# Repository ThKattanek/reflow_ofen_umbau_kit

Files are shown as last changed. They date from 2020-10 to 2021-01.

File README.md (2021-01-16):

# Reflow Ofen Umbau Kit
Mit dem „Reflow Ofen Umbau Kit“ (in Zukunft „Kit“ genannt) kann man einen alten Pizza Ofen zu einem Reflow Ofen umfunktionieren. Das Kit beinhaltet die komplette Mikrocontroller gestützte Steuerung und das entsprechende Netzteil welches die 5V und 12V bereitstellt. Dieses Kit ist für Hobbyelektroniker gedacht die hin und wieder eine Platine mit SMD Bauteilen löten wollen, jedoch eine Anschaffung eines Reflows Ofens zu kostenintensiv ist.

### [Letzte Offizelle Version findet ihr hier](https://github.com/ThKattanek/reflow_ofen_umbau_kit/releases/latest)

### YouTube Videos vom Projekt
|1.Teil|2.Teil|3.Teil|4.Teil|5.Teil|
|---|---|---|---|---|
|[](http://www.youtube.com/watch?v=8IvjsnkUP-0 "Projekt Reflow Ofen Teil 1")|[](http://www.youtube.com/watch?v=AaKD-QuOhvM "Projekt Reflow Ofen Teil 2")|[](http://www.youtube.com/watch?v=eux7afdVVEE  "Projekt Reflow Ofen Teil 3")|[](http://www.youtube.com/watch?v=xKUIrKcyTKQ "Projekt Reflow Ofen Teil 4")|[](http://www.youtube.com/watch?v=lzVyeRATymM "Projekt Reflow Ofen Teil 5")
### Hardware / Schaltplan
Die Hardware wurde mit KiCad entwickelt. Version 5.1.7 unter Ubuntu.

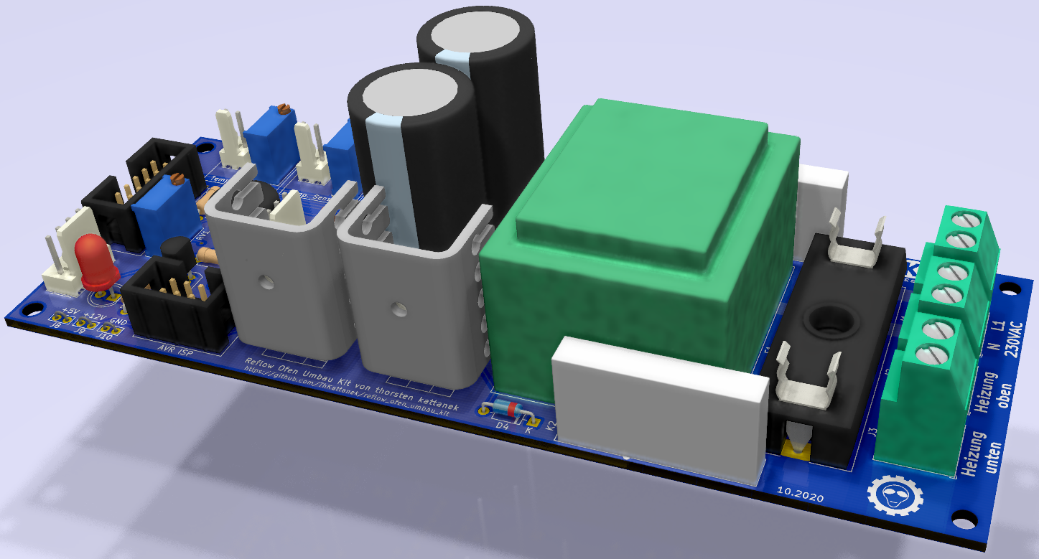
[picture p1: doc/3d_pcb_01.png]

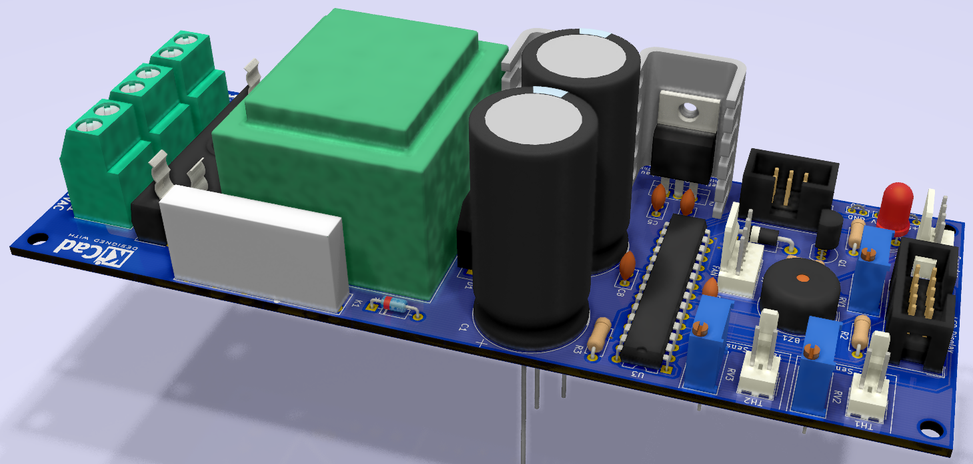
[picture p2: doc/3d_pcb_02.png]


### PCB
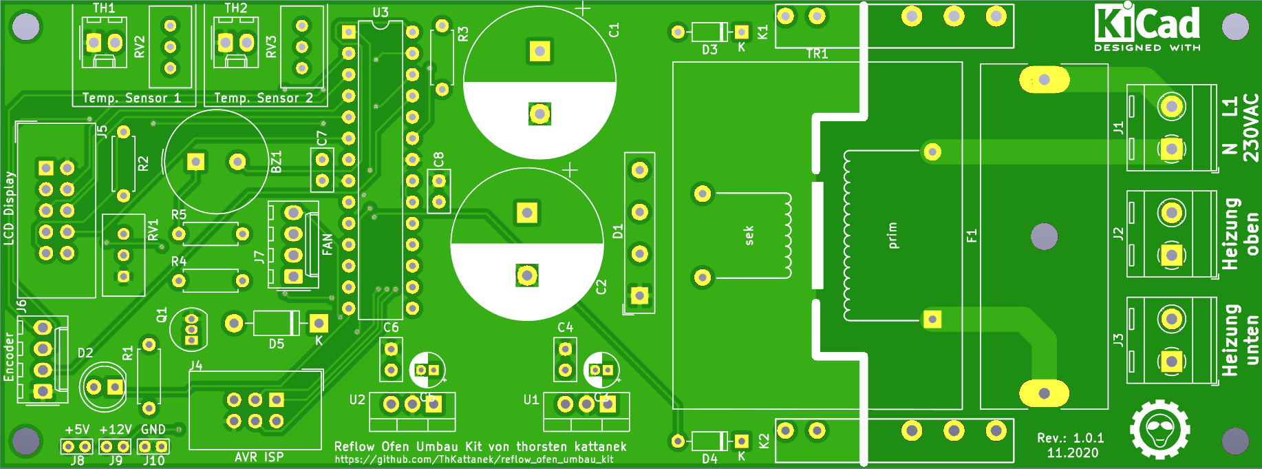
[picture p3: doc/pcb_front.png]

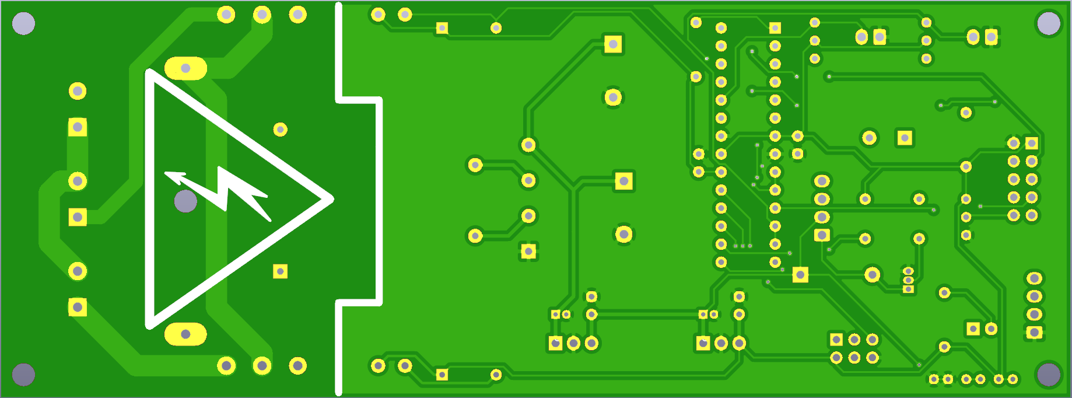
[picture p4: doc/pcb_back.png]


### Verwendete Libs
LCD Ansteuerung von Mikrokontroller.net: http://www.mikrocontroller.net/articles/AVR-GCC-Tutorial/LCD-Ansteuerung

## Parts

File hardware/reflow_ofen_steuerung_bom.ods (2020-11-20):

Reference | Quantity | Value | Footprint | Datasheet
BZ1 | 1 | Buzzer | Buzzer_Beeper:Buzzer_TDK_PS1240P02BT_D12.2mm_H6.5mm | ~
C1 C2 | 2 | 10m | Capacitor_THT:CP_Radial_D18.0mm_P7.50mm | ~
C3 C5 | 2 | 0,33u | Capacitor_THT:CP_Radial_D4.0mm_P1.50mm | ~
C4 C6 C7 C8 | 4 | 100n | Capacitor_THT:C_Disc_D5.0mm_W2.5mm_P2.50mm | ~
D1 | 1 | B40C2300-1500A | Diode_THT:Diode_Bridge_Vishay_GBL | https://diotec.com/tl_files/diotec/files/pdf/datasheets/b40c2300.pdf
D2 | 1 | LED | LED_THT:LED_D5.0mm | ~
D3 D4 | 2 | 1N4148 | Diode_THT:D_DO-35_SOD27_P7.62mm_Horizontal | https://assets.nexperia.com/documents/data-sheet/1N4148_1N4448.pdf
D5 | 1 | 1N4001 | Diode_THT:D_DO-41_SOD81_P10.16mm_Horizontal | http://www.vishay.com/docs/88503/1n4001.pdf
F1 | 1 | Fuse | Fuse:Fuseholder_Cylinder-6.3x32mm_Schurter_0031-8002_Horizontal_Open | ~
J1 | 1 | 230VAC | TerminalBlock_RND:TerminalBlock_RND_205-00287_1x02_P5.08mm_Horizontal | ~
J10 | 1 | GND | TestPoint:TestPoint_Bridge_Pitch2.0mm_Drill0.7mm | ~
J2 | 1 | Heizung oben | TerminalBlock_RND:TerminalBlock_RND_205-00287_1x02_P5.08mm_Horizontal | ~
J3 | 1 | Heizung unten | TerminalBlock_RND:TerminalBlock_RND_205-00287_1x02_P5.08mm_Horizontal | ~
J4 | 1 | AVR-ISP-6 | Connector_IDC:IDC-Header_2x03_P2.54mm_Vertical | ~
J5 | 1 | LCD Display | Connector_IDC:IDC-Header_2x05_P2.54mm_Vertical | ~
J6 | 1 | Encoder | Connector_Molex:Molex_KK-254_AE-6410-04A_1x04_P2.54mm_Vertical | ~
J7 | 1 | FAN | Connector_Molex:Molex_KK-254_AE-6410-04A_1x04_P2.54mm_Vertical | ~
J8 | 1 | +5V | TestPoint:TestPoint_Bridge_Pitch2.0mm_Drill0.7mm | ~
J9 | 1 | +12V | TestPoint:TestPoint_Bridge_Pitch2.0mm_Drill0.7mm | ~
K1 K2 | 2 | FTR-LY_Cxxx | relay_tk:FTR-LY_Cxxx | ${TK_DATASHEETS}/FTR-LY.pdf
Q1 | 1 | BC337 | Package_TO_SOT_THT:TO-92_Inline | https://diotec.com/tl_files/diotec/files/pdf/datasheets/bc337.pdf
R1 | 1 | 1,5k | Resistor_THT:R_Axial_DIN0207_L6.3mm_D2.5mm_P7.62mm_Horizontal | ~
R2 R5 | 2 | 150 | Resistor_THT:R_Axial_DIN0207_L6.3mm_D2.5mm_P7.62mm_Horizontal | ~
R3 | 1 | 10k | Resistor_THT:R_Axial_DIN0207_L6.3mm_D2.5mm_P7.62mm_Horizontal | ~
R4 | 1 | 220 | Resistor_THT:R_Axial_DIN0207_L6.3mm_D2.5mm_P7.62mm_Horizontal | ~
RV1 RV2 RV3 | 3 | 10k | Potentiometer_THT:Potentiometer_Bourns_3296W_Vertical | ~
TH1 TH2 | 2 | KTY84-130 | Connector_Molex:Molex_KK-254_AE-6410-02A_1x02_P2.54mm_Vertical | http://cache.nxp.com/documents/data_sheet/KTY84_SER.pdf?pspll=1
TR1 | 1 | GERTH_12V_3.6VA | transformer_tk:Transformer_NF_GERTH_387.12-1 | ${TK_DATASHEETS}/GERTH_DATA_TYPE-387.pdf
U1 | 1 | L7812 | Package_TO_SOT_THT:TO-220-3_Vertical | http://www.st.com/content/ccc/resource/technical/document/datasheet/41/4f/b3/b0/12/d4/47/88/CD00000444.pdf/files/CD00000444.pdf/jcr:content/translations/en.CD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
U2 | 1 | L7805 | Package_TO_SOT_THT:TO-220-3_Vertical | http://www.st.com/content/ccc/resource/technical/document/datasheet/41/4f/b3/b0/12/d4/47/88/CD00000444.pdf/files/CD00000444.pdf/jcr:content/translations/en.CD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
U3 | 1 | ATmega8-16PU | Package_DIP:DIP-28_W7.62mm | http://ww1.microchip.com/downloads/en/DeviceDoc/atmel-2486-8-bit-avr-microcontroller-atmega8_l_datasheet.pdf

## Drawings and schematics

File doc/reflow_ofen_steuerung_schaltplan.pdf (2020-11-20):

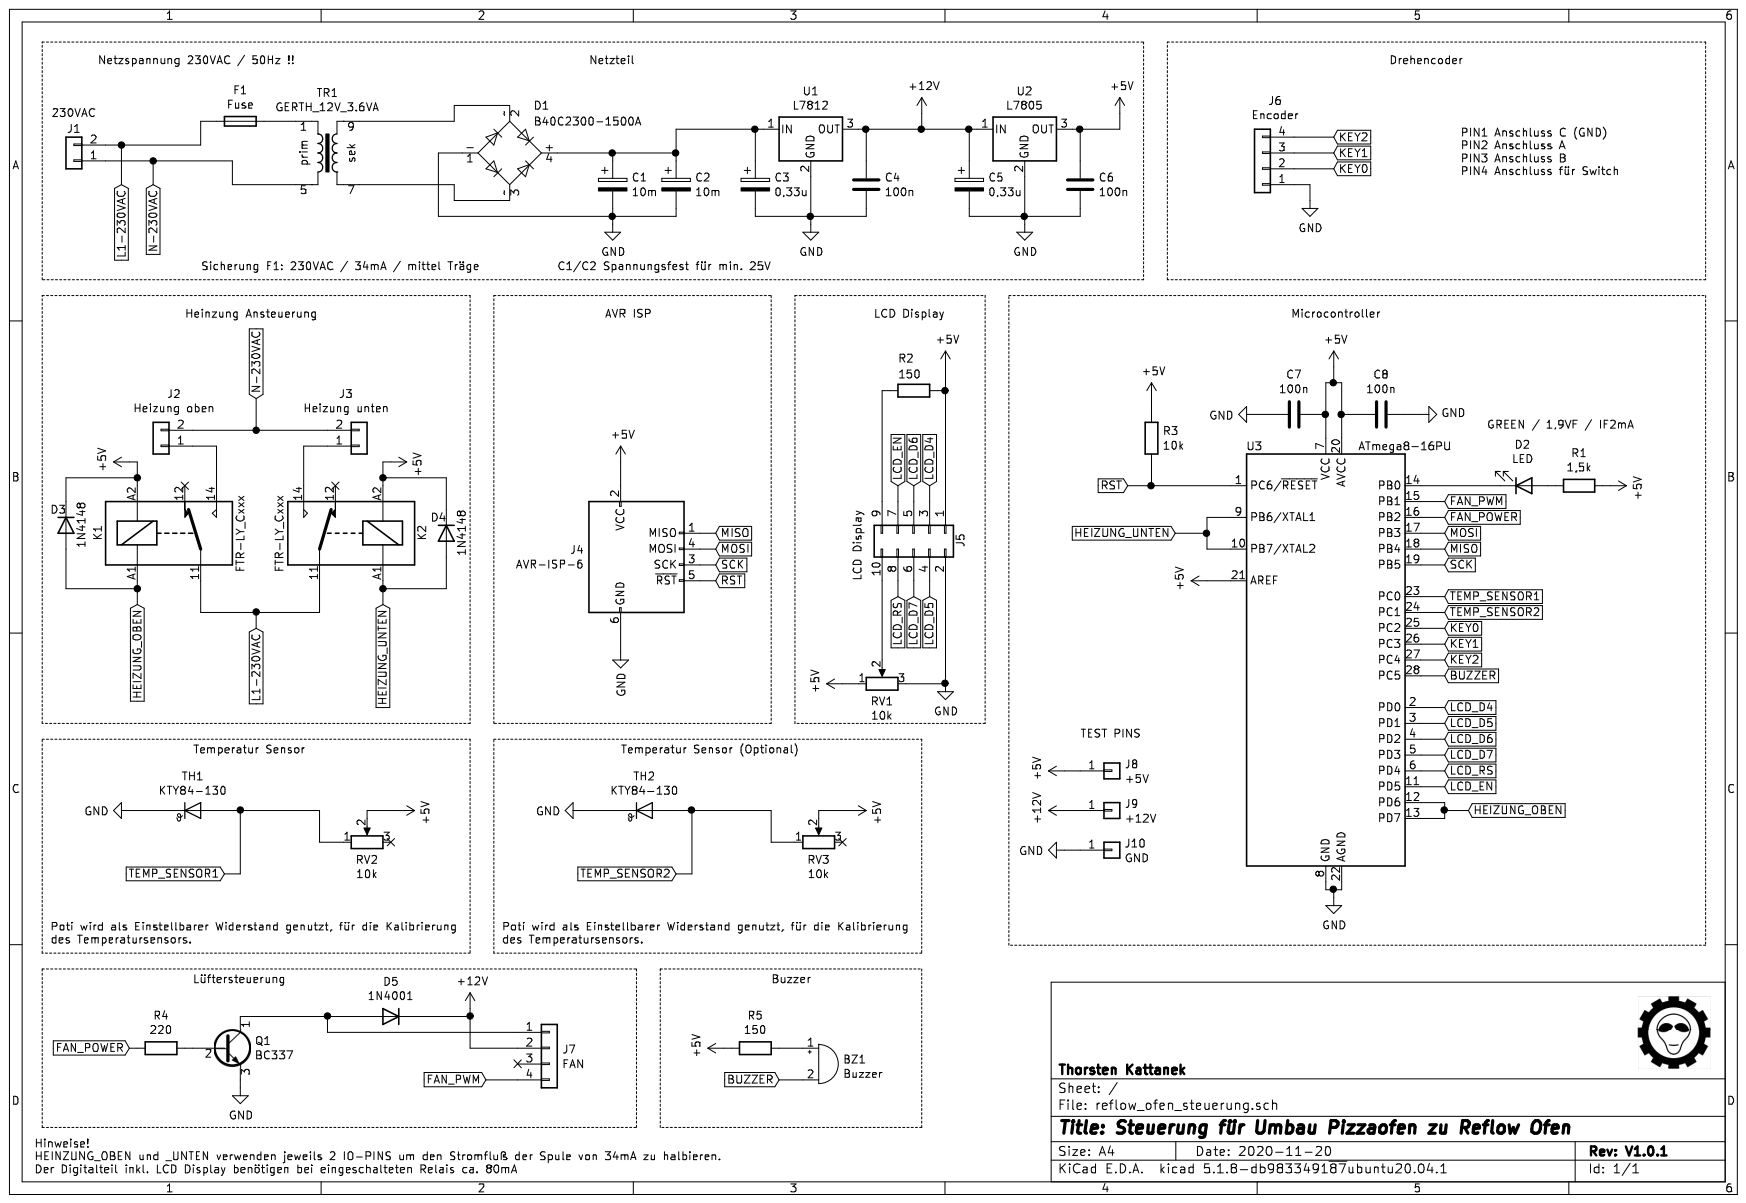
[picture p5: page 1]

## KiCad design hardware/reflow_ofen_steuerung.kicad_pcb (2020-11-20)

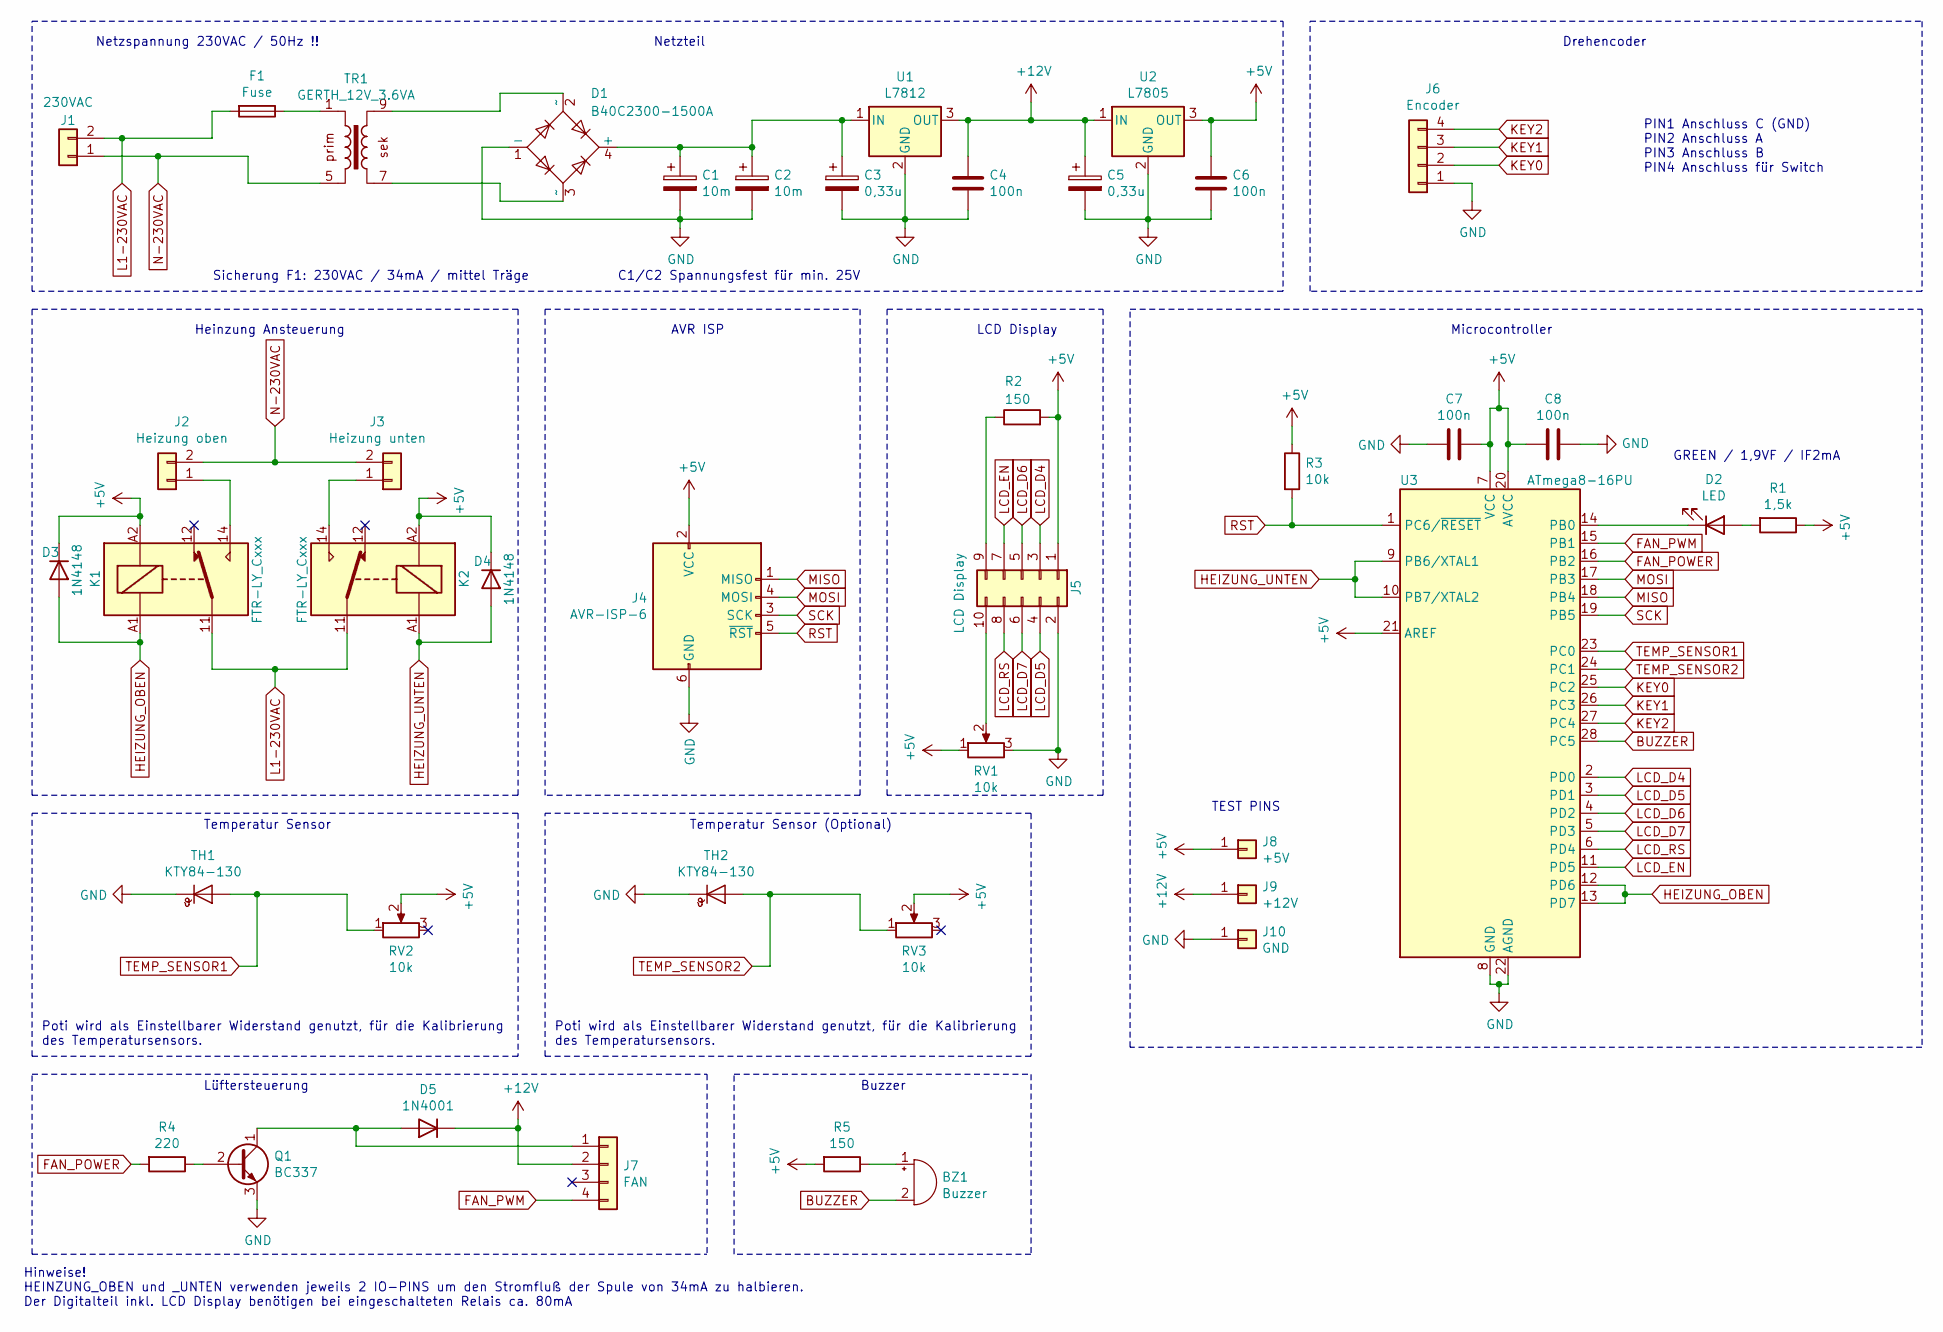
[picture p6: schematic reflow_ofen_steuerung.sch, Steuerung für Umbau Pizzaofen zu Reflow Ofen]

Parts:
BZ1: Buzzer; Buzzer_TDK_PS1240P02BT_D12.2mm_H6.5mm
C1, C2: 10m; CP_Radial_D18.0mm_P7.50mm
C3, C5: 0,33u; CP_Radial_D4.0mm_P1.50mm
C4, C6, C7, C8: 100n; C_Disc_D5.0mm_W2.5mm_P2.50mm
D1: B40C2300-1500A; Diode_Bridge_19.0x3.5x10.0mm_P5.0mm
D2: LED; LED_D5.0mm
D3, D4: 1N4148; D_DO-35_SOD27_P7.62mm_Horizontal
D5: 1N4001; D_DO-41_SOD81_P10.16mm_Horizontal
F1: Fuse; Fuseholder_Cylinder-6.3x32mm_Schurter_0031-8002_Horizontal_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
J1: 230VAC; TerminalBlock_RND_205-00287_1x02_P5.08mm_Horizontal
J2: Heizung oben; TerminalBlock_RND_205-00287_1x02_P5.08mm_Horizontal
J3: Heizung unten; TerminalBlock_RND_205-00287_1x02_P5.08mm_Horizontal
J4: AVR-ISP-6; IDC-Header_2x03_P2.54mm_Vertical
J5: LCD Display; IDC-Header_2x05_P2.54mm_Vertical
J6: Encoder; Molex_KK-254_AE-6410-04A_1x04_P2.54mm_Vertical
J7: FAN; Molex_KK-254_AE-6410-04A_1x04_P2.54mm_Vertical
J8: +5V; TestPoint_Bridge_Pitch2.0mm_Drill0.7mm
J9: +12V; TestPoint_Bridge_Pitch2.0mm_Drill0.7mm
J10: GND; TestPoint_Bridge_Pitch2.0mm_Drill0.7mm
K1, K2: FTR-LY_Cxxx
Q1: BC337; TO-92_Inline
R1: 1,5k; R_Axial_DIN0207_L6.3mm_D2.5mm_P7.62mm_Horizontal
R2, R5: 150; R_Axial_DIN0207_L6.3mm_D2.5mm_P7.62mm_Horizontal
R3: 10k; R_Axial_DIN0207_L6.3mm_D2.5mm_P7.62mm_Horizontal
R4: 220; R_Axial_DIN0207_L6.3mm_D2.5mm_P7.62mm_Horizontal
RV1, RV2, RV3: 10k; Potentiometer_Bourns_3296W_Vertical
TH1, TH2: KTY84-130; Molex_KK-254_AE-6410-02A_1x02_P2.54mm_Vertical
TR1: GERTH_12V_3.6VA; Transformer_NF_GERTH_387.12-1
U1: L7812; TO-220-3_Vertical
U2: L7805; TO-220-3_Vertical
U3: ATmega8-16PU; DIP-28_W7.62mm

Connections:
+5V: C6.1, C7.1, C8.2, D3.1 (K), D4.1 (K), J4.2 (VCC), J5.1, J8.1, K1.A2, K2.A2, R1.1, R2.2, R3.1, R5.2, RV1.1, RV2.2, RV3.2, U2.3 (OUT), U3.7 (VCC), U3.20 (AVCC), U3.21 (AREF)
+12V: C4.1, C5.1, D5.1 (K), J7.2, J9.1, U1.3 (OUT), U2.1 (IN)
BUZZER: BZ1.2 (+), U3.28 (PC5)
FAN_POWER: R4.2, U3.16 (PB2)
FAN_PWM: J7.4, U3.15 (PB1)
GND: C1.2, C2.2, C3.2, C4.2, C5.2, C6.2, C7.2, C8.1, D1.1 (-), J4.6 (GND), J5.2, J6.1, J10.1, Q1.3 (E), RV1.3, TH1.1 (K), TH2.1 (K), U1.2 (GND), U2.2 (GND), U3.8 (GND), U3.22 (AGND)
HEIZUNG_OBEN: D3.2 (A), K1.A1, U3.12 (PD6), U3.13 (PD7)
HEIZUNG_UNTEN: D4.2 (A), K2.A1, U3.9 (PB6/XTAL1), U3.10 (PB7/XTAL2)
KEY0: J6.2, U3.25 (PC2)
KEY1: J6.3, U3.26 (PC3)
KEY2: J6.4, U3.27 (PC4)
L1-230VAC: F1.2, J1.2, K1.11, K2.11
LCD_D4: J5.3, U3.2 (PD0)
LCD_D5: J5.4, U3.3 (PD1)
LCD_D6: J5.5, U3.4 (PD2)
LCD_D7: J5.6, U3.5 (PD3)
LCD_EN: J5.7, U3.11 (PD5)
LCD_RS: J5.8, U3.6 (PD4)
MISO: J4.1 (MISO), U3.18 (PB4)
MOSI: J4.4 (MOSI), U3.17 (PB3)
unnamed: J1.1, J2.2, J3.2, TR1.5
unnamed: BZ1.1 (-), R5.1
unnamed: C1.1, C2.1, C3.1, D1.4 (+), U1.1 (IN)
unnamed: D1.2 (~~), TR1.9
unnamed: D1.3 (~~), TR1.7
unnamed: D2.1 (K), U3.14 (PB0)
unnamed: D2.2 (A), R1.2
unnamed: D5.2 (A), J7.1, Q1.1 (C)
unnamed: F1.1, TR1.1
unnamed: J2.1, K1.14
unnamed: J3.1, K2.14
unnamed: J5.9, R2.1
unnamed: J5.10, RV1.2
unnamed: Q1.2 (B), R4.1
RST: J4.5 (~RST), R3.2, U3.1 (PC6/~RESET)
SCK: J4.3 (SCK), U3.19 (PB5)
TEMP_SENSOR1: RV2.1, TH1.2 (A), U3.23 (PC0)
TEMP_SENSOR2: RV3.1, TH2.2 (A), U3.24 (PC1)

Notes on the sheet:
Netzspannung 230VAC / 50Hz !!
C1/C2 Spannungsfest für min. 25V
Sicherung F1: 230VAC / 34mA / mittel Träge
Heinzung Ansteuerung
Netzteil
Microcontroller
GREEN / 1,9VF / IF2mA
LCD Display
AVR ISP
Hinweise! HEINZUNG_OBEN und _UNTEN verwenden jeweils 2 IO-PINS um den Stromfluß der Spule von 34mA zu halbieren. Der Digitalteil inkl. LCD Display benötigen bei eingeschalteten Relais ca. 80mA
Temperatur Sensor
Poti wird als Einstellbarer Widerstand genutzt, für die Kalibrierung des Temperatursensors.
Temperatur Sensor (Optional)
Drehencoder
PIN1 Anschluss C (GND) PIN2 Anschluss A PIN3 Anschluss B PIN4 Anschluss für Switch
Lüftersteuerung
Buzzer
TEST PINS

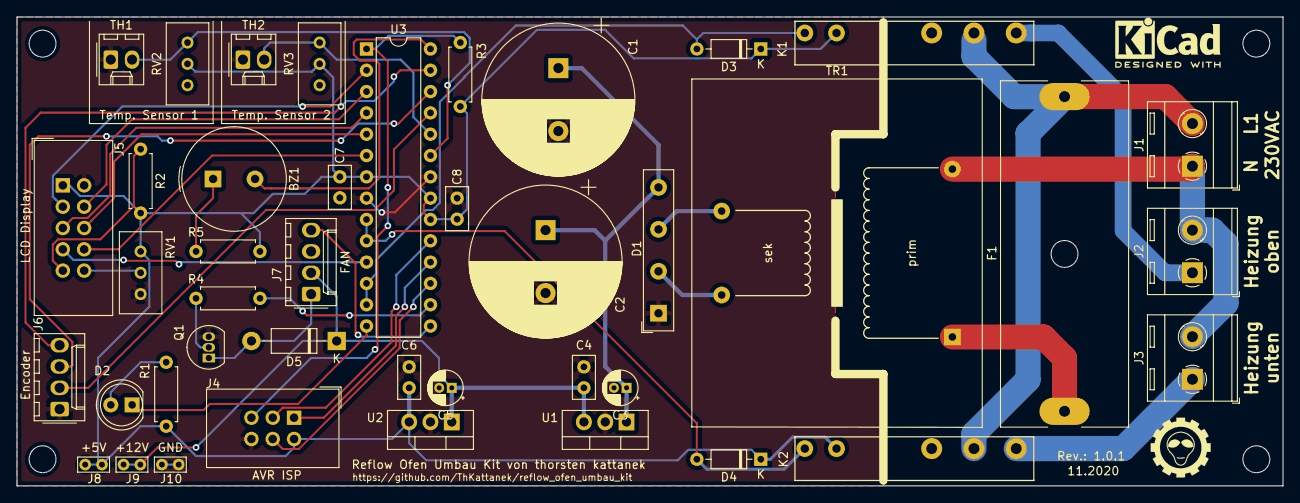
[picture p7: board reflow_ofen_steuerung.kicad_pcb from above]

Board: 2 copper layers, 150.9 x 55.9 mm, 42 parts (0 on the bottom side), 38 nets.

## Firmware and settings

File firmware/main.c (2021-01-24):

/* Name: main.c
 * Projekt: reflow_ofen_steuerung
 * Author: Thorsten Kattanek
 * Geändert am: 27.09.2020
 * Copyright: Thorsten Kattanek
 * License: GNU GPL v2 (see License.txt), GNU GPL v3 or proprietary (CommercialLicense.txt)
 *
 */

#define F_CPU   4000000UL

#include <avr/io.h>
#include <avr/wdt.h>
#include <avr/interrupt.h>
#include <util/delay.h>
#include <avr/pgmspace.h>   /* benötigt von usbdrv.h */

#include <stdio.h>

#include "./config.h"
#include "./version.h"
#include "./lcd.h"
#include "./kty84-130_teperature_table.h"

#include "./gui_constans.h"
#include "./menu.h"
#include "./settings.h"

void show_start_message(void);
void init_adc(void);
uint16_t get_adc(void);
void init_pwm(void);
void set_fan_speed(uint8_t speed);
void init_keys(void);
void init_timer2(void);
uint8_t get_key_from_buffer();
void update_gui(void);
void check_menu_events(uint16_t menu_event);
void audio_signal_final();
void audio_beep();

volatile uint8_t adc_counter = 0;
volatile uint16_t current_adc_value;
uint16_t old_adc_value;
int16_t current_temperature = 0;

// Optimal für 85°
uint16_t tempern_time = 240;                    // Tempern Zeit in minuten
uint8_t tempern_temperatur_max_start = 70;      // Tempern nach Start hier Heizung abschalten, muss dann aber min. bis tempern_temperatur kommen
uint8_t pre_heating;
uint8_t tempern_temperatur = 85;                // Tempern Max Temperatur

volatile uint16_t counter_soldering;
volatile uint32_t counter_tempern;
volatile uint32_t old_counter_tempern;
volatile uint32_t counter_tempern_max;

// gui

enum {MODE_SOLDERING, MODE_TEMPERN, MODE_MENU};
uint8_t mode = MODE_MENU;

#define PHASE_1A	(PINC & (1<<IMPULS_1A_PIN))
#define PHASE_1B	(PINC & (1<<IMPULS_1B_PIN))
const unsigned char drehimp_tab[16]PROGMEM = {0,0,2,0,0,0,0,0,1,0,0,0,0,0,0,0};

volatile uint8_t key_buffer[16];
volatile uint8_t key_buffer_r_pos;
volatile uint8_t key_buffer_w_pos;

// MENU
enum  MENU_IDS{M_START_SOLDERING, M_START_TEMPERN, M_HEATER_TOP, M_HEATER_BOTTOM, M_SETTINGS, \
              M_BACK_SETTINGS, M_TEST1, M_TEST2};

/*
enum  MENU_IDS{M_BACK, M_IMAGE, M_SETTINGS, M_INFO, \
               M_BACK_IMAGE, M_INSERT_IMAGE, M_REMOVE_IMAGE, M_WP_IMAGE, M_NEW_IMAGE, M_SAVE_IMAGE, \
               M_BACK_SETTINGS, M_PIN_PB2, M_PIN_PB3, M_SAVE_EEPROM, M_RESTART, \
               M_BACK_INFO, M_VERSION_INFO, M_SDCARD_INFO};
               */

MENU_STRUCT main_menu;
MENU_STRUCT settings_menu;

int main(void)
{
    char string0[100];

    // LCD initiallisieren

    lcd_init();

    init_keys();

    // Key Puffer leeren
    key_buffer_r_pos = 0;
    key_buffer_w_pos = 0;
    
    status_led_init();

    // Buzzer initialisieren
    buzzer_init();
    motor_power_init();
    init_pwm();

    // Startmeldung ausgeben

    show_start_message();

    uint8_t counter1 = 8;

    while (counter1 > 0) {
        buzzer_on();
         status_led_on();
        _delay_ms(50);
        buzzer_off();
         status_led_off();
        _delay_ms(50);
        counter1--;
    }

    // Fan Selfcheck
    motor_power_on();
    uint8_t fan_speed = 0;

    while(fan_speed < 255)
    {
        set_fan_speed(fan_speed);
        fan_speed++;
        _delay_ms(10);
    }

    while(fan_speed > 0)
    {
        set_fan_speed(fan_speed);
        fan_speed--;
        _delay_ms(10);
    }
    motor_power_off();

    // Heizung initialisieren
    heating_bottom_init();
    heating_top_init();

    // Init ADC
    init_adc();

    set_fan_speed(255);

    // Timer2 initialisieren und Interrupts freigeben
    init_timer2();
    sei();

    /// Menüs einrichten
    /// Hauptmenü
    MENU_ENTRY main_menu_entrys[] = {{"Starte Loetvorgang",M_START_SOLDERING,ENTRY_NORMAL,0,0},{"Starte Tempern",M_START_TEMPERN,ENTRY_NORMAL,0,0},{"Heizung oben :",M_HEATER_TOP,ENTRY_ONOFF,0,0},{"Heizung unten:",M_HEATER_BOTTOM,ENTRY_ONOFF,0,0},{"Settings",M_SETTINGS,ENTRY_MENU,0,&settings_menu}};
    MENU_ENTRY settings_menu_entrys[] = {{"TEST1",M_START_SOLDERING,ENTRY_NORMAL,0,0}, {"TEST2",M_START_SOLDERING,ENTRY_NORMAL,0,0}};

    main_menu.lcd_cursor_char = 2;  // 126 Standard Pfeil
    menu_init(&main_menu, main_menu_entrys, 5,LCD_LINE_COUNT);

    settings_menu.lcd_cursor_char = 2;  // 126 Standard Pfeil
    menu_init(&settings_menu, settings_menu_entrys, 2,LCD_LINE_COUNT);

    menu_set_root(&main_menu);

    // Zeichen für Menü More Top setzen
    uint8_t char00[] = {4,14,31,0,0,0,0,0};
    lcd_generatechar(0, char00);

    // Zeichen für Menü More Down setzen
    uint8_t char01[] = {0,0,0,0,31,14,4,0};
    lcd_generatechar(1, char01);

    // Zeichen für Menü Position setzen
    uint8_t arrow_char[] = {0,4,6,31,6,4,0,0};
    lcd_generatechar(2, arrow_char);

    uint8_t start_soldering = 0;

    while(1)
    {
        switch(mode)
        {
        case MODE_MENU:
             update_gui();
            break;
        case MODE_SOLDERING:
            if(old_adc_value != current_adc_value)
            {
                old_adc_value = current_adc_value;
                lcd_clear();

                if(current_adc_value >= 156 && current_adc_value <= 581)
                {
                    current_temperature = pgm_read_word_near(temperature_table + current_adc_value - 156);
                    sprintf(string0,"Temperatur: %d%cC", current_temperature, 0xdf);
                    lcd_string(string0);

                    if(current_temperature > 180)
                    {
                        heating_top_off();
                        heating_bottom_off();
                        if(start_soldering == 0)
                        {
                            start_soldering = 1;
                            counter_soldering = 0;
                        }
                    }
                    if(current_temperature < 180)
                    {
                        heating_top_on();
                        heating_bottom_on();
                    }

                }
                else
                {
                    lcd_string("Temperatur: Error");
                }
            }

            if(counter_soldering == 600 && start_soldering == 1)
            {
                start_soldering = 0;
                mode = MODE_MENU;
                heating_top_off();
                heating_bottom_off();

                audio_signal_final();

                menu_refresh();
            }

            if(get_key_from_buffer() == KEY2_UP)
            {
                mode = MODE_MENU;
                heating_top_off();
                heating_bottom_off();
                menu_refresh();
            }
            break;
        case MODE_TEMPERN:
            if(old_adc_value != current_adc_value)
            {
                old_adc_value = current_adc_value;

                if(current_adc_value >= 156 && current_adc_value <= 581)
                {
                    current_temperature = pgm_read_word_near(temperature_table + current_adc_value - 156);
                    lcd_setcursor(0,2);
                    sprintf(string0,"Temperatur: %d%cC   ", current_temperature, 0xdf);
                    lcd_string(string0);

                    if(current_temperature > tempern_temperatur_max_start && pre_heating)
                    {
                        heating_top_off();
                    }

                    if(current_temperature >= tempern_temperatur)
                    {
                        heating_top_off();
                        pre_heating = 0;
                    }

                    if(current_temperature < tempern_temperatur && !pre_heating)
                    {
                        heating_top_on();
                    }
                }
                else
                {
                    lcd_string("Temperatur: Error");
                }
            }

            if(old_counter_tempern != counter_tempern)
            {
                old_counter_tempern = counter_tempern;

                uint16_t time_seconds = (counter_tempern_max - old_counter_tempern) / 20;
                uint16_t minutes = time_seconds / 60;
                uint16_t seconds = time_seconds % 60;
                lcd_setcursor(0,3);
                sprintf(string0,"Restzeit: %3.3d:%2.2d", minutes, seconds);
                //sprintf(string0,"CounterMax: %d", counter_tempern_max);
                lcd_string(string0);

                char string1[21];
                string1[20] = 0;
                uint16_t t = (old_counter_tempern * 20) / counter_tempern_max;
                lcd_setcursor(0,4);
                for(uint8_t i=0; i <t; i++)
                    lcd_data('*');
            }

            if(counter_tempern >= counter_tempern_max)
            {
                mode = MODE_MENU;
                heating_top_off();
                heating_bottom_off();
                audio_signal_final();
                menu_refresh();
            }

            if(get_key_from_buffer() == KEY2_UP)
            {
                mode = MODE_MENU;
                heating_top_off();
                heating_bottom_off();
                menu_refresh();
            }
            break;
         }
    }
}

/////////////////////////////////////////////////////////////////////

void show_start_message(void)
{
    lcd_clear();
    lcd_setcursor( 1, 1);
    lcd_string("- Reflow Ofen Kit -");
    lcd_setcursor( 2,2);
    lcd_string("Firmware:  ");
    lcd_string(VERSION);
    lcd_setcursor( 0,4);
    lcd_string("by thorsten kattanek");
    _delay_ms(START_MESSAGE_TIME);
    lcd_clear();
}

/////////////////////////////////////////////////////////////////////

void init_adc(void)
{
    ADMUX = 1 << REFS0 | 1 << REFS1;                // using external reference 5.0V,  result is right adjusted
    ADCSRA = 1 << ADEN | 1 << ADPS1 | 1 << ADPS2;   // enable adc // ADC Prescaler set of 64 (62,5kHz ADC Clock)
}

uint16_t get_adc(void)
{
    ADCSRA |= (1 << ADSC);          // start conversion
    while(ADCSRA & (1 << ADSC));    // wait of finish conversion
    return ADC;                     // return ADC0
}

void init_pwm(void)
{
    DDRB |= 1 << PB1;                                   // OC1A auf Ausgang setzen
    TCCR1A |= 1 << COM1A1 | /*1 << WGM13 |*/ 1 << WGM12 | /*1 << WGM11 |*/ 1 << WGM10;     // OC0A non-invertmode - FAST PWM Mode 10Bit
    TCCR1B |= 1 << CS10;                                 // Prescaler auf 8 --> 8MHz / 8 / 256 = 3,9 KHz
    OCR1A = 0;   // 0 - 1023
}

void set_fan_speed(uint8_t speed)
{
    OCR1A = speed;
}

void init_keys(void)
{
    // Entsprechende Ports auf Eingangschalten
    KEY0_DDR &= ~(1<<KEY0);
    KEY1_DDR &= ~(1<<KEY1);
    KEY2_DDR &= ~(1<<KEY2);

    // Interne Pullup Setzen
    KEY0_PORT |= 1<<KEY0;
    KEY1_PORT |= 1<<KEY1;
    KEY2_PORT |= 1<<KEY2;
}


void init_timer2(void)
{
    // Interrunpt auf 500Hz
    TCCR2 |= (1 << WGM21) | (1 << CS20) | (1 << CS21);  // CTC Mode / Normal port operation, OC2 disconnected / Prescaler 32
    OCR2 = 250; // Timer Top = 250
    TIMSK |= (1 << OCIE2); // Output Compare Match Interrupt Enable
}

ISR(TIMER2_COMP_vect)
{
    volatile static uint8_t counter0 = 0;
    volatile static uint16_t counter1 = 0;
    volatile static uint8_t key2_is_pressed = 0;
    volatile static uint8_t key2_next_up_is_invalid = 0;

    volatile static uint8_t old_drehgeber = 0;
    uint8_t pos_change;	// 0=keine Änderung 1=hoch 2=runter

    volatile static uint8_t old_key2 = 0;

    // Wird alle 2ms aufgerufen

    // Encoder
    old_drehgeber = (old_drehgeber << 2)  & 0x0F;
    if (PHASE_1A) old_drehgeber |=2;
    if (PHASE_1B) old_drehgeber |=1;
    pos_change = (char)pgm_read_byte(&drehimp_tab[old_drehgeber]);

    switch(pos_change)
    {
    case 1:
        key_buffer[key_buffer_w_pos++] = KEY0_DOWN;
        break;
    case 2:
        key_buffer[key_buffer_w_pos++] = KEY1_DOWN;
        break;
    default:
        break;
    }
    key_buffer_w_pos &= 0x0f;

    if(counter0 < 25)
    {
        counter0++;
        return;
    }

    counter0 = 0;

    // Ab hier alle 50ms

    counter1++;
    counter_soldering++;
    counter_tempern++;

    current_adc_value = get_adc();
    uint8_t key2 = get_key2();



    if(key2 != old_key2)
    {
        if(key2)
        {
            key_buffer[key_buffer_w_pos++] = KEY2_DOWN;
            counter1 = 0;
            key2_is_pressed = 1;
        }
        else
        {
            if(!key2_next_up_is_invalid)
                key_buffer[key_buffer_w_pos++] = KEY2_UP;
            key2_is_pressed = 0;
            key2_next_up_is_invalid = 0;
        }
    }

    if(key2_is_pressed && counter1 == TIMEOUT1_KEY2)
    {
        key_buffer[key_buffer_w_pos++] = KEY2_TIMEOUT1;
        key2_next_up_is_invalid = 1;
    }

    if(key2_is_pressed && counter1 == TIMEOUT2_KEY2)
    {
        key_buffer[key_buffer_w_pos++] = KEY2_TIMEOUT2;
        key2_next_up_is_invalid = 1;
    }

    key_buffer_w_pos &= 0x0f;
    old_key2 = key2;

}

uint8_t get_key_from_buffer()
{
    if(key_buffer_r_pos != key_buffer_w_pos)
    {
        uint8_t val = key_buffer[key_buffer_r_pos++];
        key_buffer_r_pos &= 0x0f;
        return  val;
    }
    else
        return NO_KEY;
}

void update_gui(void)
{
    uint8_t key_code = get_key_from_buffer();
    check_menu_events(menu_update(key_code));
}

void check_menu_events(uint16_t menu_event)
{
    uint8_t command = menu_event >> 8;
    uint8_t value = menu_event & 0xff;

    switch(command)
    {
    case MC_EXIT_MENU:
        audio_signal_final();
        break;

    case MC_SELECT_ENTRY:
        switch(value)
        {
        case M_START_SOLDERING:
            audio_beep();
            heating_top_on();
            heating_bottom_on();
            mode = MODE_SOLDERING;
            break;

        case M_START_TEMPERN:
            audio_beep();
            lcd_clear();
            lcd_string("Tempern...");
            heating_top_on();
            pre_heating = 1;
            counter_tempern_max = (uint32_t)tempern_time * 60 * 20;
            counter_tempern = old_counter_tempern = 0;
            mode = MODE_TEMPERN;
            break;

        case M_HEATER_TOP:
            audio_beep();
            if(menu_get_entry_var1(&main_menu, M_HEATER_TOP))
            {
                heating_top_on();
            }
            else
            {
                heating_top_off();
            }
            menu_refresh();
            break;

        case M_HEATER_BOTTOM:
            audio_beep();
            if(menu_get_entry_var1(&main_menu, M_HEATER_BOTTOM))
            {
                heating_bottom_on();
            }
            else
            {
                heating_bottom_off();
            }
            menu_refresh();
            break;
        }

    /*
    case MC_EXIT_MENU:
        set_gui_mode(GUI_INFO_MODE);
        break;

    case MC_SELECT_ENTRY:
        switch(value)
        {
        /// Main Menü

        /// Image Menü
        case M_INSERT_IMAGE:
            set_gui_mode(GUI_FILE_BROWSER);
            break;
        case M_REMOVE_IMAGE:
            remove_image();
            set_gui_mode(GUI_INFO_MODE);
            break;
        case M_WP_IMAGE:
            if(akt_image_type != G64_IMAGE)
                menu_set_entry_var1(&image_menu, M_WP_IMAGE, 1);

            if(menu_get_entry_var1(&image_menu, M_WP_IMAGE))
                set_write_protection(1);
            else
                set_write_protection(0);
                menu_refresh();
            break;

        /// Settings Menü
        case M_PIN_PB2:
            if(menu_get_entry_var1(&settings_menu, M_PIN_PB2))
            {
                DDRB |= 1<<PB2;
            }
            else
            {
                DDRB &= ~(1<<PB2);
            }
            menu_refresh();
            break;

        case M_PIN_PB3:
            if(menu_get_entry_var1(&settings_menu, M_PIN_PB3))
            {
                DDRB |= 1<<PB3;
            }
            else
            {
                DDRB &= ~(1<<PB3);
            }
            menu_refresh();
            break;

        case M_SAVE_EEPROM:
            break;

        case M_RESTART:
            exit_main = 0;
            break;

        /// Info Menü
        case M_VERSION_INFO:
            show_start_message();
            menu_refresh();
            break;

        case M_SDCARD_INFO:
            show_sdcard_info_message();
            menu_refresh();
            break;
        }
        break;
        */
    }
}

void audio_signal_final()
{
    buzzer_on();
    _delay_ms(1000);
    buzzer_off();
    _delay_ms(500);
    buzzer_on();
    _delay_ms(1000);
    buzzer_off();
    _delay_ms(500);
    buzzer_on();
    _delay_ms(1000);
    buzzer_off();
}

void audio_beep()
{
    buzzer_on();
    _delay_ms(30);
    buzzer_off();
}

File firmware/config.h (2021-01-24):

/* Name: config.h
 * Projekt: reflow_ofen_steuerung
 * Author: Thorsten Kattanek
 * Geändert am: 27.09.2020
 * Copyright: Thorsten Kattanek
 * License: GNU GPL v2 (see License.txt), GNU GPL v3 or proprietary (CommercialLicense.txt)
 *
 */ 

// Konfiguration /////////////////////////////////////////////////

// LCD
#define LCD_LINE_COUNT 4
#define LCD_LINE_SIZE 20

// Zeit in ms wie lange die Version nach dem Start angezeigt wird
#define START_MESSAGE_TIME 1500

// Status LED Cofiguration --> PortB Pin0
#define STATUS_LED_PORT     PORTB
#define STATUS_LED_DDR      DDRB
#define STATUS_LED_PIN      PIN0

// Einabetasten
#define KEY0_DDR DDRC
#define KEY0_PORT PORTC
#define KEY0_PIN PINC
#define KEY0	 PINC3

#define KEY1_DDR DDRC
#define KEY1_PORT PORTC
#define KEY1_PIN PINC
#define KEY1	 PINC2

#define KEY2_DDR DDRC
#define KEY2_PORT PORTC
#define KEY2_PIN PINC
#define KEY2	 PINC4

#define get_key0() (~KEY0_PIN & (1<<KEY0))
#define get_key1() (~KEY1_PIN & (1<<KEY1))
#define get_key2() (~KEY2_PIN & (1<<KEY2))


#define IMPULS_1A_PIN KEY1
#define IMPULS_1A_PORT KEY1_PORT
#define IMPULS_1A_DDR KEY1_DDR

#define IMPULS_1B_PIN KEY0
#define IMPULS_1B_PORT KEY0_PORT
#define IMPULS_1B_DDR KEY0_DDR

// Heizungsteuerung
// Heizung unten
#define HEATING_BOTTOM_PORT   PORTB
#define HEATING_BOTTOM_DDR    DDRB
#define HEATING_BOTTOM_PIN    PIN6

// Heizung oben
#define HEATING_TOP_PORT   PORTD
#define HEATING_TOP_DDR    DDRD
#define HEATING_TOP_PIN    PIN6

// Buzzer (Dauerton)
#define BUZZER_PORT     PORTC
#define BUZZER_DDR      DDRC
#define BUZZER_PIN      PIN5

// Motor Power
#define MOTOR_POWER_PORT     PORTB
#define MOTOR_POWER_DDR      DDRB
#define MOTOR_POWER_PIN      PIN2

// Temperatur Sensor 1
#define SENSOR1_PORT    PORTC
#define SENSOR1_DDR     DDRC
#define SENSOR1_PIN     PIN0

// Temperatur Sensor 2 (Optional)
#define SENSOR2_PORT    PORTC
#define SENSOR2_DDR     DDRC
#define SENSOR2_PIN     PIN1

/////////////////////////////////////////////////////////////////////////////////////////////

#define status_led_init() STATUS_LED_DDR |= 1 << STATUS_LED_PIN; STATUS_LED_PORT |= 1 << STATUS_LED_PIN
#define status_led_on() STATUS_LED_PORT &= ~(1 << STATUS_LED_PIN)
#define status_led_off() STATUS_LED_PORT |= 1 << STATUS_LED_PIN

#define heating_bottom_init() HEATING_BOTTOM_DDR |= 0x03 << HEATING_BOTTOM_PIN; HEATING_BOTTOM_PORT |= 0x03 << HEATING_BOTTOM_PIN
#define heating_top_init() HEATING_TOP_DDR |= 0x03 << HEATING_TOP_PIN; HEATING_TOP_PORT |= 0x03 << HEATING_TOP_PIN

#define heating_bottom_on() HEATING_BOTTOM_PORT &= ~(0x03 << HEATING_BOTTOM_PIN)
#define heating_top_on() HEATING_TOP_PORT &= ~(0x03 << HEATING_TOP_PIN)

#define heating_bottom_off() HEATING_BOTTOM_PORT |= 0x03 << HEATING_BOTTOM_PIN
#define heating_top_off() HEATING_TOP_PORT |= 0x03 << HEATING_TOP_PIN

#define buzzer_init() BUZZER_DDR |= 0x03 << BUZZER_PIN; BUZZER_PORT |= 0x03 << BUZZER_PIN
#define buzzer_on() BUZZER_PORT &= ~(0x03 << BUZZER_PIN)
#define buzzer_off() BUZZER_PORT |= 0x03 << BUZZER_PIN

#define motor_power_init() MOTOR_POWER_DDR |= 1 << MOTOR_POWER_PIN
#define motor_power_on() MOTOR_POWER_PORT |= 1 << MOTOR_POWER_PIN
#define motor_power_off() MOTOR_POWER_PORT &= ~(1 << MOTOR_POWER_PIN)

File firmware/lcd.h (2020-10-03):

// Ansteuerung eines HD44780 kompatiblen LCD im 4-Bit-Interfacemodus
// http://www.mikrocontroller.net/articles/AVR-GCC-Tutorial/LCD-Ansteuerung
//
 
#ifndef LCD_ROUTINES_H
#define LCD_ROUTINES_H
 
////////////////////////////////////////////////////////////////////////////////
// Hier die verwendete Taktfrequenz in Hz eintragen, wichtig!
 
#ifndef F_CPU
#define F_CPU 4000000UL
#endif
 
////////////////////////////////////////////////////////////////////////////////
// Pinbelegung für das LCD, an verwendete Pins anpassen
// Alle LCD Pins müssen an einem Port angeschlossen sein und die 4
// Datenleitungen müssen auf aufeinanderfolgenden Pins liegen
 
//  LCD DB4-DB7 <-->  PORTD Bit PD0-PD3
#define LCD_PORT      PORTD
#define LCD_DDR       DDRD
#define LCD_DB        PD0
 
//  LCD RS      <-->  PORTD Bit PD4     (RS: 1=Data, 0=Command)
#define LCD_RS        PD4
 
//  LCD EN      <-->  PORTB Bit PB5     (EN: 1-Impuls für Daten)
#define LCD_EN        PD5
 
////////////////////////////////////////////////////////////////////////////////
// LCD Ausführungszeiten (MS=Millisekunden, US=Mikrosekunden)
 
#define LCD_BOOTUP_MS           15 	// 15
#define LCD_ENABLE_US           20	// 20
#define LCD_WRITEDATA_US        46	// 46
#define LCD_COMMAND_US          42	// 42
 
#define LCD_SOFT_RESET_MS1      5	// 5
#define LCD_SOFT_RESET_MS2      1	// 1
#define LCD_SOFT_RESET_MS3      1	// 1
#define LCD_SET_4BITMODE_MS     5	// 5
 
#define LCD_CLEAR_DISPLAY_MS    2	// 2	
#define LCD_CURSOR_HOME_MS      2	// 2
 
////////////////////////////////////////////////////////////////////////////////
// Zeilendefinitionen des verwendeten LCD
// Die Einträge hier sollten für ein LCD mit einer Zeilenlänge von 20 Zeichen passen
// Bei anderen Zeilenlängen müssen diese Einträge angepasst werden
 
#define LCD_DDADR_LINE1         0
#define LCD_DDADR_LINE2         64
#define LCD_DDADR_LINE3         20
#define LCD_DDADR_LINE4         84
 
////////////////////////////////////////////////////////////////////////////////
// Initialisierung: muss ganz am Anfang des Programms aufgerufen werden.
void lcd_init( void );
 
////////////////////////////////////////////////////////////////////////////////
// LCD löschen
void lcd_clear( void );
 
////////////////////////////////////////////////////////////////////////////////
// Cursor in die 1. Zeile, 0-te Spalte
void lcd_home( void );
 
////////////////////////////////////////////////////////////////////////////////
// Cursor an eine beliebige Position 
void lcd_setcursor( uint8_t spalte, uint8_t zeile );
 
////////////////////////////////////////////////////////////////////////////////
// Ausgabe eines einzelnen Zeichens an der aktuellen Cursorposition 
void lcd_data( uint8_t data );
 
////////////////////////////////////////////////////////////////////////////////
// Ausgabe eines Strings an der aktuellen Cursorposition 
void lcd_string( const char *data );
 
////////////////////////////////////////////////////////////////////////////////
// Schreibt einen String auf das LCD mit erweiterten Parametern
// start:   Position des erstes Zeichens im String was ausgegeben werden soll
// length:  Maximale Anzahl der Zeichen die Ausgegeben werden sollen
void lcd_print(char *string, uint8_t start, uint8_t length);

////////////////////////////////////////////////////////////////////////////////
// Definition eines benutzerdefinierten Sonderzeichens.
// data muss auf ein Array[8] mit den Zeilencodes des zu definierenden Zeichens
// zeigen
void lcd_generatechar( uint8_t code, const uint8_t *data );
 
////////////////////////////////////////////////////////////////////////////////
// Ausgabe eines Kommandos an das LCD.
void lcd_command( uint8_t data );
 
 
////////////////////////////////////////////////////////////////////////////////
// LCD Befehle und Argumente.
// Zur Verwendung in lcd_command
 
// Clear Display -------------- 0b00000001
#define LCD_CLEAR_DISPLAY       0x01
 
// Cursor Home ---------------- 0b0000001x
#define LCD_CURSOR_HOME         0x02
 
// Set Entry Mode ------------- 0b000001xx
#define LCD_SET_ENTRY           0x04
 
#define LCD_ENTRY_DECREASE      0x00
#define LCD_ENTRY_INCREASE      0x02
#define LCD_ENTRY_NOSHIFT       0x00
#define LCD_ENTRY_SHIFT         0x01
 
// Set Display ---------------- 0b00001xxx
#define LCD_SET_DISPLAY         0x08
 
#define LCD_DISPLAY_OFF         0x00
#define LCD_DISPLAY_ON          0x04
#define LCD_CURSOR_OFF          0x00
#define LCD_CURSOR_ON           0x02
#define LCD_BLINKING_OFF        0x00
#define LCD_BLINKING_ON         0x01
 
// Set Shift ------------------ 0b0001xxxx
#define LCD_SET_SHIFT           0x10
 
#define LCD_CURSOR_MOVE         0x00
#define LCD_DISPLAY_SHIFT       0x08
#define LCD_SHIFT_LEFT          0x00
#define LCD_SHIFT_RIGHT         0x04
 
// Set Function --------------- 0b001xxxxx
#define LCD_SET_FUNCTION        0x20
 
#define LCD_FUNCTION_4BIT       0x00
#define LCD_FUNCTION_8BIT       0x10
#define LCD_FUNCTION_1LINE      0x00
#define LCD_FUNCTION_2LINE      0x08
#define LCD_FUNCTION_5X7        0x00
#define LCD_FUNCTION_5X10       0x04
 
#define LCD_SOFT_RESET          0x30
 
// Set CG RAM Address --------- 0b01xxxxxx  (Character Generator RAM)
#define LCD_SET_CGADR           0x40
 
#define LCD_GC_CHAR0            0
#define LCD_GC_CHAR1            1
#define LCD_GC_CHAR2            2
#define LCD_GC_CHAR3            3
#define LCD_GC_CHAR4            4
#define LCD_GC_CHAR5            5
#define LCD_GC_CHAR6            6
#define LCD_GC_CHAR7            7
 
// Set DD RAM Address --------- 0b1xxxxxxx  (Display Data RAM)
#define LCD_SET_DDADR           0x80
 
#endif 

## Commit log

2020-10-07 PCB angepasst für Kühlkörper der Spannungsregler
    [reflow_ofen_steuerung.kicad_pcb, reflow_ofen_steuerung.sch]
2020-10-14 changed screenshots from 3d pcb
2020-10-22 added 150 ohm resistor for buzzer
    [reflow_ofen_steuerung.kicad_pcb, reflow_ofen_steuerung.sch]
2020-10-22 added buzzer in config.h and main.c
    [config.h, main.c]
2020-10-23 added gerber files
    [reflow_ofen_steuerung-B_Cu.gbr, reflow_ofen_steuerung-B_Mask.gbr, reflow_ofen_steuerung-B_SilkS.gbr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]
2020-10-23 added 3d fuse model in fuse holder footprint
    [reflow_ofen_steuerung.kicad_pcb]
2020-10-24 changed label ADC0/1 to TEMP_SENSOR1/2
    [reflow_ofen_steuerung-B_Cu.gbr, reflow_ofen_steuerung-B_Mask.gbr, reflow_ofen_steuerung-B_SilkS.gbr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]
2020-10-27 changed firmware: added fan control
2020-10-27 changed firmware: test fanspeed with temperature sensor
2020-11-18 added bom
    [reflow_ofen_steuerung_bom.ods]
2020-11-20 Brückengleichrichter D1 korrigiert
    [reflow_ofen_steuerung-B_Cu.gbr, reflow_ofen_steuerung-B_Mask.gbr, reflow_ofen_steuerung-B_SilkS.gbr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]
2021-01-16 firmware: added menu und first soldering program
